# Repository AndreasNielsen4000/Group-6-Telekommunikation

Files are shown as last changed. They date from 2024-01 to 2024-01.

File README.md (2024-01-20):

# Security Access system
Created for course 34338 - Telecommunication programming projects with Arduino.

A door access security system for everyday use. The implemented log-on possibilities are RFID, PIN, and bluetooth from a mobile phone.

The system consists of three parts:

1. A node.js server running a temporary database (by design so we did not need to clear the database all the time).
2. An ESP8266 with:
   1. RFID Reader.
   2. Servo Motor ("Door/Lock").
   3. Buzzer.
3. An ESP32-WROOM-32 with:
   1. Liquid Crystal Display for user feedback as well as access admin menu.
   2. keypad.
   3. RGB LED for feedback.
   4. White LED ("Keypad light").
   5. Photoresistor (Controlling White LED).
   
If a user enters a PIN on the keypad, a request with a hashed version of the PIN is sent from the ESP32 to the ESP8266. If the ESP8266 has WiFi, it will pass the request on to the server.
If the response is valid and access is granted, the ESP8266 will open the door and send a request to the ESP32 to update the LCD and as well as the RGB LED.

If a user presents an RFID tag, and the ESP8266 has WiFi, it will pass the request on to the server.
If the response is valid and access is granted, the ESP8266 will open the door and send a request to the ESP32 to update the LCD and as well as the RGB LED.

Should the response in either case be invalid or access not granted, then the door will not open, and a request will be sent from the ESP8266 to the ESP32 to change the LCD and RGB LED accordingly.

Should the ESP8266 not have a WiFi connection, it will instead look in the EEPROM to check if a match is stored there.

On any access granted or access denied response from the server, the ESP8266 checks the locally stored information and any needed update to the local information is performed. This is only done on event-by-event basis, meaning not the entire local user database is updated each time.

## Responsibilities

| Functionalities | Main | Secondary|
|---|---|---|
| API | Mads | Maria |
| Server | Maria | Mads |
| LCD | Andreas | Alexander, Maria |
| LEDs | Mads | Maria |
| Buzzer | Christian | Lukas |
| Serial communication | Alexander | Lukas, Mads, Andreas |
| EEPROM | Lukas | Christian |
| RFID | Christian | Lukas |
| Keypad | Andreas | Alexander |
| Photoresistor | Maria | Mads |
| WiFi | Lukas | Mads |
| Bluetooth | Alexander | |
| Hash | Andreas | |
| Servo motor | Christian | |
|Final integration | Lukas, Alexander, Mads | |

## Circuit diagram
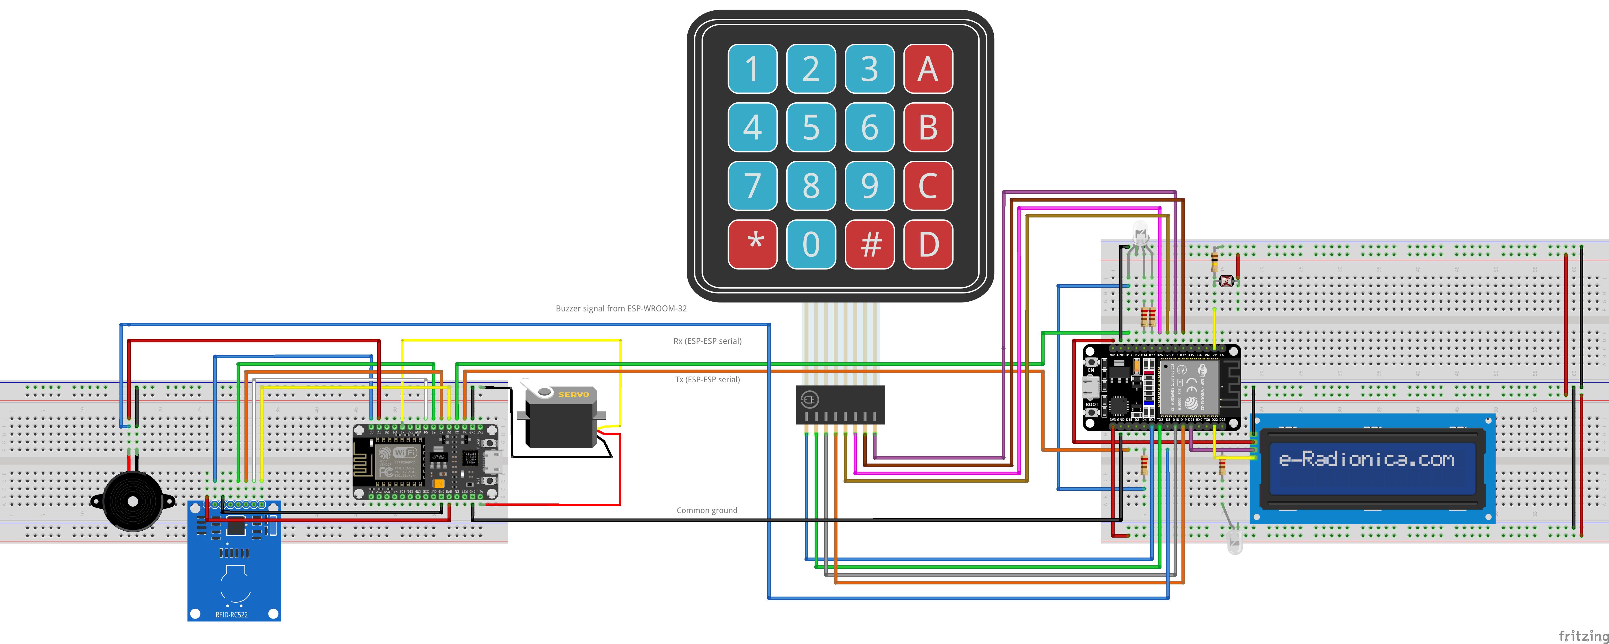
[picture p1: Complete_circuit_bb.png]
Complete setup


## Video Preview of Functionality

https://github.com/AndreasNielsen4000/Group-6-Telekommunikation/assets/8758884/5dff1484-a8b8-44ab-9b94-1a6748f98a57

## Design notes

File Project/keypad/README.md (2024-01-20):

# Keypad_ESP

## Keypad_ESP
Code for keypad part of project involving door access control running on two ESPs and a webserver.

## lcd_display
Code with class and functions to easily control the LCD display connected to the Keypad ESP.

## led_display
Code with class and functions to easily control status LED, light LED and buzzer sound on keypad keypress.

## hash
Simple function to hash passwords and RFID tags.

## Syntax for Serial Communication between ESPs

### From Keypad ESP to RFID ESP
Syntax:

 `<COMMAND>,<hashedPassword>(optional),<userIndex>(optional),<hashedMasterPassword>(optional)`

### Commands
From Keypad ESP to RFID ESP

`LOGIN`

`NEW_PASSWORD`

`NEW_RFID`

`CANCEL_RFID`

From RFID ESP to Keypad ESP

`ACCESS`

`ACCESS_DENIED`

`RFID_READ`

### Examples & Description:
#### User Login:
A login with a password (PIN) is attempted from the keypad.

Keypad Sends:

`LOGIN,<hashedPassword>, , `

#### New User Password:
From the admin menu on the keypad, a request to register a new password for a user is sent.

Keypad Sends:

`NEW_PASSWORD,<hashedPassword>,<userIndex>,<hashedMasterPassword>`

#### New User RFID:
From the admin menu on the keypad, a request to register a new RFID chip/card for a user is sent.

Keypad Sends:

`NEW_RFID, ,<userIndex>,<hashedMasterPassword>`

Cancel RFID registration: (Only used for information as the RFID part has a timeout of no key is presented)

`CANCEL_RFID, , , `

### From RFID ESP To Keypad ESP
Syntax: 

`<COMMAND>,<userIndex>(optional)`

### Examples:
#### User Has Logged In:
If a login was processed and access granted RFID ESP sends:

`ACCESS,<userIndex>`

#### Wrong Password:
If a login was processed and access denied RFID ESP sends:

`ACCESS_DENIED,`

#### New User RFID created:
After a new RFID has been read, the RFID ESP sends the following command to verify that the Keypad ESP can exit the menu:

`RFID_READ,`

If instead an RFID chip was not read or an error occured the RFID ESP will send:

`ACCESS_DENIED,`

## Circuit diagram
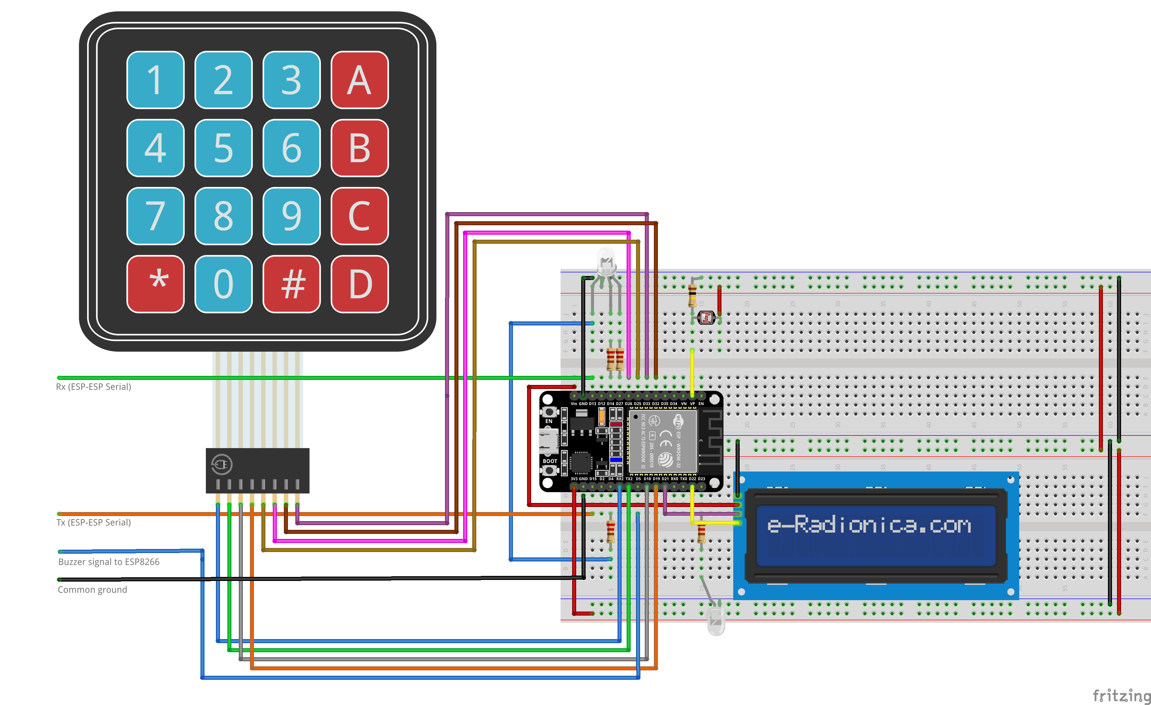
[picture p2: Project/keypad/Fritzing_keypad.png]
ESP32 Keypad setup


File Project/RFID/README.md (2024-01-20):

# RFID

## RFID
Code for RFID part of project involving door access control running on two ESPs and a webserver.

## api_caller
Library to support the requests and responses to/from the server

## hash
Simple function to hash passwords and RFID tags.

## Syntax for Serial Communication between ESPs

### From Keypad ESP to RFID ESP
Syntax:

 `<COMMAND>,<hashedPassword>(optional),<userIndex>(optional),<hashedMasterPassword>(optional)`

### Commands
From Keypad ESP to RFID ESP

`LOGIN`

`NEW_PASSWORD`

`NEW_RFID`

`CANCEL_RFID`

From RFID ESP to Keypad ESP

`ACCESS`

`ACCESS_DENIED`

`RFID_READ`

### Examples & Description:
#### User Login:
A login with a password (PIN) is attempted from the keypad.

Keypad Sends:

`LOGIN,<hashedPassword>, , `

#### New User Password:
From the admin menu on the keypad, a request to register a new password for a user is sent.

Keypad Sends:

`NEW_PASSWORD,<hashedPassword>,<userIndex>,<hashedMasterPassword>`

#### New User RFID:
From the admin menu on the keypad, a request to register a new RFID chip/card for a user is sent.

Keypad Sends:

`NEW_RFID, ,<userIndex>,<hashedMasterPassword>`

Cancel RFID registration: (Only used for information as the RFID part has a timeout of no key is presented)

`CANCEL_RFID, , , `

### From RFID ESP To Keypad ESP
Syntax: 

`<COMMAND>,<userIndex>(optional)`

### Examples:
#### User Has Logged In:
If a login was processed and access granted RFID ESP sends:

`ACCESS,<userIndex>`

#### Wrong Password:
If a login was processed and access denied RFID ESP sends:

`ACCESS_DENIED,`

#### New User RFID created:
After a new RFID has been read, the RFID ESP sends the following command to verify that the Keypad ESP can exit the menu:

`RFID_READ,`

If instead an RFID chip was not read or an error occured the RFID ESP will send:

`ACCESS_DENIED,`

## Circuit diagram
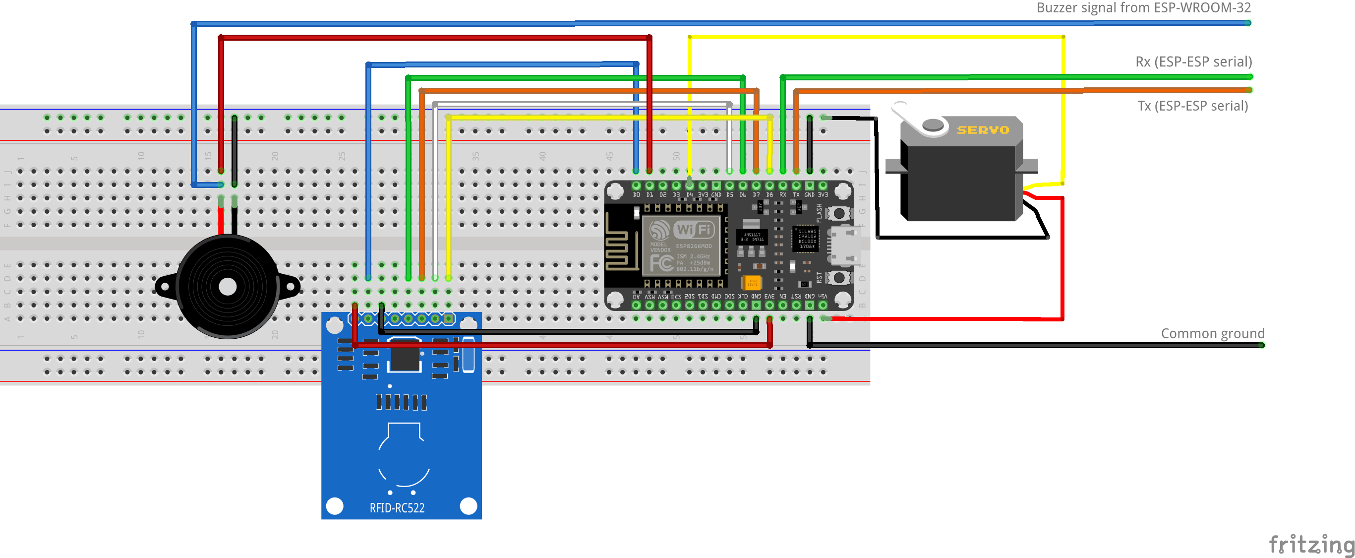
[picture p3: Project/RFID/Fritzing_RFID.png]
ESP8266 RFID setup


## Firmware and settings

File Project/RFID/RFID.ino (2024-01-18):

/*
  RFID.ino - This file contains the code for an ESP-based RFID system.
  It includes functionality for RFID input, EEPROM, serial communication between ESPs, WiFi setup and use of api_caller.
  It is meant to be used with an ESP8266 and communicates with another ESP through serial communication.
*/

#include <ArduinoJson.h>
#include <ESP8266HTTPClient.h>
#include <ESP8266WiFi.h>
#include <ESP_EEPROM.h>
#include <MFRC522.h>
#include <SPI.h>
#include <Servo.h>
#include <WiFiClientSecure.h>
#include <optional>

#include "Hash.h"
#include "api_caller.h"

#define SS_PIN D8 //MFRC522 SS pin ("slave select")
#define RST_PIN D0  //RESET pin for MFRC522
#define BUZZER_PIN D1 // Buzzer pin
#define NUM_USERS 5 // Number of users that can be saved in memory at the same time
#define KEYCARD_LENGTH 11 // Length of the keycard UID in bytes
#define MAX_MESSAGE_LENGTH 50 // Max length of the message from serial in bytes
#define OPEN_DOOR_TIME 5000  // The time the door is open in milliseconds
#define RFID_INTERVAL 5000  // Interval in milliseconds between RFID read
#define WIFI_INTERVAL 1000  // Interval in milliseconds between WiFi read
#define NEW_RFID_TIMEOUT 10000 // Time to read a new RFID before a timeout in milliseconds

MFRC522 mfrc522(SS_PIN, RST_PIN);  // Create MFRC522 instance.
Servo door_servo;

// Wifi credentials
const char *ssid = "";   /* Your SSID */
const char *pass = "";   /* Your Password */

const char *apiUrl = "http://172.20.10.5:8080"; /* Your API URL. Example: "https://api.example.com" */

// Global variables
unsigned long previous_RFID_Millis = 0;  // Will store last time the RFID was read
unsigned long previous_WIFI_Millis = 0;  // Will store last time the WIFI was updated
unsigned long currentMillis;
unsigned long adminPassword = hashPassword("12345678"); // adminpassword for the system

WiFiClient client;
ApiCaller apiCaller = ApiCaller(client, apiUrl);

// Struct for storing a user in memory (the pin and rfid are hashed)
struct User {
  unsigned long pin;
  unsigned long rfid;
};

// The array where the users are stored in memory (the pin and rfid are hashed)
User users[NUM_USERS] = {};

//Enum for the different received serial commands
enum SerialCommand {
  LOGIN,
  NEW_PASSWORD,
  NEW_RFID,
  CANCEL_RFID,
};

//Enum for the different serial responses
enum SerialSend {
  ACCESS_GRANTED,
  ACCESS_DENIED,
  RFID_READ,
  PIN_READ,
};

//Struct to store the command from serial communication and the associated data
struct CommandStruct {
  SerialCommand command;
  std::optional<unsigned long> password;
  std::optional<int> userIndex;
  std::optional<unsigned long> adminPassword;
};

struct ApiStruct {
  bool authenticated;
  int id;
};

bool connected_to_wifi(char retry_times);
std::optional<CommandStruct> processSerialCommunication();
void sendSerialResponse(SerialSend serialSend, int userIndex = -1);

void setup() {
  Serial.begin(115200);  // Initiate a serial communication

  EEPROM.begin(sizeof(User) * NUM_USERS);  // Initiate EEPROM memory size
  SPI.begin();                               // Initiate SPI bus
  mfrc522.PCD_Init();                        // Initiate MFRC522

  door_servo.attach(D4, 500, 2400);  // Attaches the servo on pin D4 to the servo object
  pinMode(BUZZER_PIN, OUTPUT);

  initialize_user_array_from_eeprom(); // Read the users array from EEPROM

  connected_to_wifi(3); // Try to connect to wifi 3 times
}

void loop() {
  // The loop is written in two parts, one for serial input and one for RFID input, serial input is based on the optionalCommand

  std::optional<CommandStruct> optionalCommand = processSerialCommunication();
  //Serial input section
  // There is a command from serial to be executed
  if (optionalCommand.has_value()) {
    CommandStruct cmd = optionalCommand.value();

    switch (cmd.command)
    {
    case SerialCommand::LOGIN: {
      // Check if the password is correct
      // in either api or local if no internet
      // save in EEPROM from API if it has changed
      if (connected_to_wifi(0)) {
        Serial.println("Calling api to check data");

        std::unique_ptr<DynamicJsonDocument> doc = apiCaller.GET("/pin", String(cmd.password.value()));
        if (doc == nullptr) {
          sendSerialResponse(SerialSend::ACCESS_DENIED);
          return;
        } 

        if (doc->containsKey("authenticated") ) {
          bool authenticated = (*doc)["authenticated"].as<bool>();
          if (authenticated) {
            int id = (*doc)["id"].as<int>();
            sendSerialResponse(SerialSend::ACCESS_GRANTED, id);
            if (users[id].pin != cmd.password.value()) {
              Serial.println("Found password in server but not in EEPROM, adding password to EEPROM");
              compare_and_update_pin(id, cmd.password.value());
            }
            
            access_tone();
            //Add to EEPROM at the correct index
            return;
          } else {
            sendSerialResponse(SerialSend::ACCESS_DENIED);
            for (int i = 0; i < NUM_USERS; i++) {
            if (users[i].pin == cmd.password.value()) {
              Serial.println("Found password in EEPROM but not in server, deleting from EEPROM");
              compare_and_update_pin(i, 0);
            }
          }
            no_access_tone();
            //If code is in EEPROM, remove it
            return;
          }
        } else {
          sendSerialResponse(SerialSend::ACCESS_DENIED);
          no_access_tone();
          return;
        }
        
      } else {
        bool access_granted = false;
        // Look in EEPROM
        for (int i = 0; i < NUM_USERS; i++) {
          if (users[i].pin == cmd.password.value()) {
            access_granted = true;
            sendSerialResponse(SerialSend::ACCESS_GRANTED, i);
            access_tone();
            return;
          }
        }

        if (access_granted == false) {
          sendSerialResponse(SerialSend::ACCESS_DENIED);
          no_access_tone();
        }
      }

      break; // LOGIN
    }
    case SerialCommand::NEW_RFID: {

      // You need to be connected to wifi to change the RFID
      if (!connected_to_wifi(0)) {
          sendSerialResponse(SerialSend::ACCESS_DENIED);
          return;
      }

      if (!cmd.adminPassword.has_value()) {
        Serial.println("No admin password");
        return;
      }

      // Check if the admin password is correct
      if (cmd.adminPassword.value() != adminPassword) {
        sendSerialResponse(SerialSend::ACCESS_DENIED);
        break;
      };

      // Get the new rfid code
      bool has_read_rfid = false;
      long new_rfid_millis = millis();

      unsigned long new_hashed_rfid = 0;

      do {
        if (!mfrc522.PICC_IsNewCardPresent()) {
          currentMillis = millis();
          continue;
        }
        if (!mfrc522.PICC_ReadCardSerial()) {
          continue;
        }
        Serial.println("Has read data");

        new_hashed_rfid = hashPassword(read_RFID().c_str());
        Serial.println(new_hashed_rfid);
        has_read_rfid = true;
      } while (!has_read_rfid && currentMillis - new_rfid_millis < NEW_RFID_TIMEOUT);

      if (!has_read_rfid) {
        sendSerialResponse(SerialSend::ACCESS_DENIED);
        break;
      }

      std::unique_ptr<DynamicJsonDocument> doc = apiCaller.PUT("/rfid", String(cmd.userIndex.value()), String(new_hashed_rfid));
      if (doc == nullptr) {
        sendSerialResponse(SerialSend::ACCESS_DENIED);
        break;
      } 

      if (doc->containsKey("success")) {
        bool succeeded = (*doc)["success"].as<bool>();
        if (succeeded) {

          Serial.println("Updated RFID");
          // Update the rfid in memory
          compare_and_update_rfid(cmd.userIndex.value(), new_hashed_rfid);

          sendSerialResponse(SerialSend::RFID_READ, cmd.userIndex.value());
          access_tone();
        } else {
          Serial.println("Failed to update RFID");
          sendSerialResponse(SerialSend::ACCESS_DENIED);
          no_access_tone();
        }
      } else {
        Serial.println("Failed to update RFID");
        sendSerialResponse(SerialSend::ACCESS_DENIED);
        no_access_tone();
      }

      break; // NEW_RFID
    }
    case SerialCommand::NEW_PASSWORD: {
      // You need to be connected to wifi to change the password
      if (!connected_to_wifi(0)) {
          sendSerialResponse(SerialSend::ACCESS_DENIED);
          return;
      }

      if (!cmd.adminPassword.has_value() && !cmd.password.has_value()) {
        Serial.println("No admin password or password");
        return;
      }

      // Check if the admin password is correct
      if (cmd.adminPassword.value() != adminPassword) {
        sendSerialResponse(SerialSend::ACCESS_DENIED);
        break;
      }

      std::unique_ptr<DynamicJsonDocument> doc = apiCaller.PUT("/pin", String(cmd.userIndex.value()), String(cmd.password.value()));
      if (doc == nullptr) {
        sendSerialResponse(SerialSend::ACCESS_DENIED);
        break;
      } 

      if (doc->containsKey("success")) {
        bool succeeded = (*doc)["success"].as<bool>();
        if (succeeded) {

          Serial.println("Updated PIN");
          // Update the pin in memory
          compare_and_update_pin(cmd.userIndex.value(), cmd.password.value());

          sendSerialResponse(SerialSend::PIN_READ, cmd.userIndex.value());
          access_tone();
        } else {
          Serial.println("Failed to update PIN");
          sendSerialResponse(SerialSend::ACCESS_DENIED);
          no_access_tone();
        }
      } else {
        Serial.println("Failed to update PIN");
        sendSerialResponse(SerialSend::ACCESS_DENIED);
        no_access_tone();
      }

    }
    default:
      // Should never reach here
      break;
    }
  }

  // RFID input section
    // Look for new cards
  if (!mfrc522.PICC_IsNewCardPresent()) {
    return;
  }
  // Select one of the cards
  if (!mfrc522.PICC_ReadCardSerial()) {
    return;
  }

  // Only read the UID if it is over the interval length since it has last been read
  currentMillis = millis();
  if (currentMillis - previous_RFID_Millis > RFID_INTERVAL) {
    bool access_granted = false;

    // Call api
    if (connected_to_wifi(0)) {
      Serial.println("Calling api to check data");
      unsigned long new_hashed_rfid = hashPassword(read_RFID().c_str());

      std::unique_ptr<DynamicJsonDocument> doc = apiCaller.GET("/rfid", String(new_hashed_rfid));
      if (doc == nullptr) {
        sendSerialResponse(SerialSend::ACCESS_DENIED);
        return;
      } 

      if (doc->containsKey("authenticated") ) {
        bool authenticated = (*doc)["authenticated"].as<bool>();
        if (authenticated) {
          int id = (*doc)["id"].as<int>();

          sendSerialResponse(SerialSend::ACCESS_GRANTED, id);
          
          if (users[id].rfid != new_hashed_rfid) {
            Serial.println("Found RFID in server but not in EEPROM, adding RFID to EEPROM");
            compare_and_update_rfid(id, new_hashed_rfid);
          }

          access_tone();
          return;
        } else {
          sendSerialResponse(SerialSend::ACCESS_DENIED);
          for (int i = 0; i < NUM_USERS; i++) {
            if (users[i].rfid == new_hashed_rfid) {
              Serial.println("Found RFID in EEPROM but not in server, deleting from EEPROM");
              compare_and_update_rfid(i, 0);
            }
          }
          
          no_access_tone();
          return;
        }
      } else {
        sendSerialResponse(SerialSend::ACCESS_DENIED);
        no_access_tone();
        return;
      }

    }

    // Look in EEPROM
    for (int i = 0; i < NUM_USERS; i++) {
      if (users[i].rfid == hashPassword(read_RFID().c_str())) {
        sendSerialResponse(SerialSend::ACCESS_GRANTED, i);
        access_granted = true;
        access_tone();
        break;
      }
    }

    if (access_granted == false) {
      sendSerialResponse(SerialSend::ACCESS_DENIED);
      no_access_tone();
    }
  }
}

/**
* Reads the UID of the RFID by collecting each byte together in on String
* Uses the MFRC522.h to read the bytes from the RFID
*
* @return the read RFID UID as a String
*/
String read_RFID() {
  previous_RFID_Millis = currentMillis;

  String content = "";

  byte letter;
  for (byte i = 0; i < mfrc522.uid.size; i++) { // Read 4 bytes from the RFID
    content.concat(String(mfrc522.uid.uidByte[i] < 0x10 ? " 0" : " "));// Add a leading zero to the UID bytes
    content.concat(String(mfrc522.uid.uidByte[i], HEX));  // Add the UID bytes to the content String
  }
  content.toUpperCase();
  return content.substring(1);  // return the UID
}


/*
* Save all of the pins and UIDs from the EEPROM to the user array
*/
void initialize_user_array_from_eeprom() {
  // Read the users array from EEPROM
  for (int i = 0; i < NUM_USERS; i++) {
    // Calculate the EEPROM address for the current user
    int address = i * sizeof(User);

    // Read the user data from EEPROM
    EEPROM.get(address, users[i]);
  }
}


/**
* Compares the new hashed pin with the old hashed pin and updates the pin if they are different
* It updates the pin in memory (users array) and in EEPROM
*
* @param user_index: the index of the user in the users array
* @param new_hashed_pin: the new hashed pin
*/
void compare_and_update_pin(int user_index, unsigned long new_hashed_pin) {
  if (users[user_index].pin != new_hashed_pin) {
    // Update the pin in user array
    users[user_index].pin = new_hashed_pin;

    // Update the pin in EEPROM
    int address = (user_index * 2) * sizeof(long);
    EEPROM.put(address, new_hashed_pin);
    EEPROM.commit();
  }
}  

/** 
* Compares the new hashed rfid with the old hashed rfid and updates the rfid if they are different
* It updates the rfid in memory (users array) and in EEPROM
*
* @param user_index: the index of the user in the users array
* @param new_hashed_rfid: the new hashed rfid
*/
void compare_and_update_rfid(int user_index, unsigned long new_hashed_rfid) {
  if (users[user_index].rfid != new_hashed_rfid) {
    // Update the rfid in user array
    users[user_index].rfid = new_hashed_rfid;

    // Update the rfid in EEPROM
    int address = (user_index * 2 + 1) * sizeof(long);
    EEPROM.put(address, new_hashed_rfid);
    EEPROM.commit();
  }
}

/*
* Plays a melody when the access is granted, and then the door opens and closes after a specified time
*/
void access_tone() {
  tone(BUZZER_PIN, 1046.5);
  delay(200);
  tone(BUZZER_PIN, 1174.66);
  delay(200);
  tone(BUZZER_PIN, 1318.51);
  delay(200);
  noTone(BUZZER_PIN);
  delay(800);
  tone(BUZZER_PIN, 1396.91);
  open_door();
  delay(300);
  noTone(BUZZER_PIN);
  delay(OPEN_DOOR_TIME - 300);
  close_door();
}

/**
* Plays a melody when the access was denied
*/
void no_access_tone() {
  tone(BUZZER_PIN, 932.33);
  delay(500);
  tone(BUZZER_PIN, 880);
  delay(500);
  tone(BUZZER_PIN, 830.61);
  delay(800);
  noTone(BUZZER_PIN);
}


void open_door() {
  door_servo.write(180);
}

void close_door() {
  door_servo.write(100);
}

/**
 * Connect to wifi with a number of retries
 *
 * @param retry_times: number of times to retry connecting to wifi. Default is 0
 * @return true if connected to wifi, false otherwise
 */
bool connected_to_wifi(char retry_times = 0){
  if (WiFi.status() == WL_CONNECTED) {
    Serial.println("Already connected to WiFi");
    return true;
  }
  Serial.println("WiFi not connected, connecting to WiFi SSID " + String(ssid));
  WiFi.begin(ssid, pass);
  // Waiting for WIFI connection
  char i = 0;
  while (WiFi.status() != WL_CONNECTED && i < retry_times) {
    delay(500);
    i++;
  }

  return WiFi.status() == WL_CONNECTED;
}

/**
 * Reads the serial input and processes it to extract command information.
 * 
 * @return An optional CommandStruct object containing the extracted command information, or std::nullopt if no commands were sent.
 */
std::optional<CommandStruct> processSerialCommunication() {
  // Read serial input
  char serialInput[MAX_MESSAGE_LENGTH] = {'\0'};
  CommandStruct commandStruct;
  commandStruct.adminPassword = std::nullopt;
  commandStruct.password = std::nullopt;
  commandStruct.userIndex = std::nullopt;

  if (Serial.available()) { // Check if there is serial data available
    Serial.readBytesUntil('\n', serialInput, MAX_MESSAGE_LENGTH);
    char* token = strtok(serialInput, ","); // Split the serial message using comma as the delimiter
    if (strcmp(token, "LOGIN") == 0) {
      commandStruct.command = SerialCommand::LOGIN;
    } else if (strcmp(token, "NEW_PASSWORD") == 0) {
      commandStruct.command = SerialCommand::NEW_PASSWORD;
    } else if (strcmp(token, "NEW_RFID") == 0) {
      commandStruct.command = SerialCommand::NEW_RFID;
    } else if (strcmp(token, "CANCEL_RFID") == 0) {
      commandStruct.command = SerialCommand::CANCEL_RFID;
    } else {
      // No commands sent
      return std::nullopt;
    }
    Serial.print("Command: ");
    Serial.println(commandStruct.command);  
    token = strtok(NULL, ","); // Get the next token (password)
    if (token != NULL && strlen(token) > 0 && strcmp(token, " ") != 0) {
      commandStruct.password = strtoul(token, NULL, 10); // Convert the password string to an unsigned long integer
      Serial.print("Password: ");
      Serial.println(commandStruct.password.value());
    }
    token = strtok(NULL, ","); // Get the next token (user index)
    if (token != NULL && strlen(token) > 0 && strcmp(token, " ") != 0) {
      commandStruct.userIndex = atoi(token); // Convert the user index string to an integer
      Serial.print("User index: ");
      Serial.println(commandStruct.userIndex.value());
    }
    token = strtok(NULL, ","); // Get the next token (admin password)
    if (token != NULL && strcmp(token, " ") != 0) {
      commandStruct.adminPassword = strtoul(token, NULL, 10); // Convert the admin password string to an unsigned long integer
      Serial.print("Admin password: ");
      Serial.println(commandStruct.adminPassword.value());
    }
    return commandStruct;
  }

  // No commands sent
  return std::nullopt;
}

/**
 * Sends a serial response based on the given SerialSend value and user index.
 * 
 * @param serialSend The type of serial response to send (ACCESS_GRANTED, ACCESS_DENIED, or RFID_READ).
 * @param userIndex The index of the user associated with the response, or -1 if no user is associated with the response.
 */
void sendSerialResponse(SerialSend serialSend, int userIndex) {
  switch (serialSend) {
    case SerialSend::ACCESS_GRANTED: //Access granted
      Serial.println("ACCESS," + String(userIndex));
      break;
    case SerialSend::ACCESS_DENIED: //Access denied
      Serial.println("ACCESS_DENIED," + String(userIndex));
      break;
    case SerialSend::RFID_READ: //We have read an RFID
      Serial.println("RFID_READ," + String(userIndex));
      break;
    default:
      break; // Should never reach here
  }
}

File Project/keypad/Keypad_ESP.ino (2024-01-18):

/*
  Keypad_ESP.ino - This file contains the code for an ESP-based keypad system.
  It includes functionality for keypad input, LCD display, LED control, and serial communication between ESPs.
  It is meant to be used with an ESP32 and communicates with another ESP through serial communication.
*/

#include <Keypad.h>
#include "Hash.h"
#include "lcd_display.h"
#include "led_control.h"
#include <BleSerial.h>

// Constants
#define MAX_MESSAGE_LENGTH 9
#define MAX_SERIAL_MESSAGE_LENGTH 150
#define NUM_USERS 5
#define RXD2 13 //define RX pin for serial2 communication (between ESPs)
#define TXD2 15 //define TX pin for serial2 communication (between ESPs)
// Pins for LED, light sensor and buzzer
#define RED_LED 4
#define GREEN_LED 14
#define BLUE_LED 27
#define WHITE_LED 23
#define LDR_PIN 36
#define BUZZER_PIN 5
// Rows and columns for keypad and keypad initialization
#define ROW_NUM 4 
#define COLUMN_NUM 4
//Keypad setup created with help from: https://arduinogetstarted.com/tutorials/arduino-keypad
byte rowPins[ROW_NUM] = {16, 17, 18, 19}; //connect to the row pinouts of the keypad
byte columnPins[COLUMN_NUM] = {25, 26, 32, 33}; //connect to the column pinouts of the keypad

// Variables for user and menu index
int menuIndex = 0;
int userIndex = 0;

// Function declarations
void adminMenuKeyPad(char *serialMessage);

char keypadKeys[ROW_NUM][COLUMN_NUM] = {
  {'1','2','3', 'A'},
  {'4','5','6', 'B'},
  {'7','8','9', 'C'},
  {'*','0','#', 'D'}
};


Keypad keypad = Keypad( makeKeymap(keypadKeys), rowPins, columnPins, ROW_NUM, COLUMN_NUM );

// Password for admin access
unsigned long adminPassword = hashPassword("12345678");

// Object declarations for LCD display, LED control and Bluetooth serial communication
lcd_display lcdDisplay;
led_control ledControl(RED_LED, GREEN_LED, BLUE_LED, WHITE_LED, LDR_PIN, BUZZER_PIN);
BleSerial SerialBT;

void setup() {
  Serial.begin(115200);
  Serial2.begin(115200, SERIAL_8N1, RXD2, TXD2);
  SerialBT.begin("KeypadBT"); //Bluetooth device name
  Serial.println("The device started, now you can pair it with bluetooth!");
  lcdDisplay.init();
  lcdDisplay.enterPasswordLCD("default"); //initial menu on lcd
  ledControl.init();
}

void loop() {
  char message[MAX_MESSAGE_LENGTH] = {'\0'}; //message array for keypad input
  char serialMessage[MAX_SERIAL_MESSAGE_LENGTH] = {'\0'}; //message array for serial input

  //Start main menu keypad function, changes the message array with keypad inputs
  mainMenuKeyPad(message, serialMessage);
  
  unsigned long messageHash = hashPassword(message);   
  ledControl.controlLED(0); //Set LED to idle status
  
  //If messageHash is not equal to the hash of an empty string, send the password to the other ESP through serial
  if (messageHash != hashPassword("\0")) {
    Serial2.println(String("LOGIN") + "," + String(messageHash) + "," + " " + ",");
    Serial.println(String("LOGIN") + "," + String(messageHash) + "," + " " + ",");
  }

  // If serialMessage is not empty, split the serial message from other ESP into message, accessGranted and userIndex, serial prints for debugging
  if (serialMessage[0] != '\0' && serialMessage[0] != '\r') {
    Serial.println("Serial message received from serial: " + String(serialMessage));
    parseSerialResponse(serialMessage);
  }
}

/**
 * Parses the serial response message and updates the access status based on the received information.
 * 
 * @param serialMessage The serial response message to parse.
 */
void parseSerialResponse(char *serialMessage) {
  int userIndex = -1;
  bool accessGranted = false;
  String tempMessage = "";
  tempMessage = serialMessage;
  char *token = strtok(serialMessage, ",");
  if (strcmp(token, "ACCESS") == 0) {
    accessGranted = true;
  } else if (strcmp(token, "ACCESS_DENIED") == 0) {
    accessGranted = false;
  } else {  // Not a valid message, must be a debug message from the other ESP - print it to the serial monitor and return
    Serial.println("Received: " + tempMessage);
    return;
  }
  token = strtok(NULL, ",");
  if (token != NULL) {
    userIndex = atoi(token);
  } else {
    userIndex = -1; // Set a default value for userIndex if not provided
  }
  updateAccessStatus(accessGranted, userIndex); //Gives feedback to user if password is correct or not through LED and LCD
}

/**
 * mainMenuKeyPad reads the keypad input in the main menu and performs actions based on the input.
 * It allows for the user to enter a password and send it to the other ESP through serial communication.
 * It also allows for the user to enter the admin menu by pressing D.
 * If the admin menu is entered, the adminMenuKeyPad function is called.
 * 
 * @param message The character array to store the keypad input message.
 * @param serialMessage The character array to store the serial input message.
 */
void mainMenuKeyPad(char *message, char *serialMessage) {
    static unsigned int messagePos = 0; // int to keep track of the position in the message array
    bool keyReceived = false;
    
    // Checking for keypad input, serial input, and Bluetooth input
    while (!keyReceived) {
        // If there is data available to read from the serial port, read it into the serial message buffer and exit the function
        if (checkSerialCommunication(serialMessage)) {
            if (messagePos > 0) {
                messagePos = 0;
                message[messagePos] = '\0';
            }
            return;
        }

        // Check if there is data available to read from the Bluetooth serial
        if (SerialBT.available()) {
            // Read the incoming data until a newline character is encountered
            String temp = SerialBT.readStringUntil('\n');
            // Convert the read String into a character array and store it in 'message'
            temp.toCharArray(message, temp.length() + 1);
            // If there is a message position, null-terminate the message at that position
            // and reset the message position
            if (messagePos > 0) {
                message[messagePos] = '\0';
                messagePos = 0;
                // Set the flag to indicate a key has been received
                keyReceived = true;
            }
            // Print a debug message to the serial monitor
            Serial.println("Serial BT message received in mainMenuKeyPad()");
            // Send a confirmation message back over Bluetooth serial
            SerialBT.println("Received");
            // Exit the function early since a key has been received
            return;
        }

        char key = keypad.getKey(); // Read keypad input
        ledControl.readLightSensor(); // Control light sensor
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

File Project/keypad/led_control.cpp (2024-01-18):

/*
* led_control.cpp
* Class and methods for controlling the LED and light sensor for the keypad
*/

#include "led_control.h"

led_control::led_control(int redPin, int greenPin, int bluePin, int lightPin, int ldrPin, int buzzerPin) : 
              PIN_RED(redPin), PIN_GREEN(greenPin), PIN_BLUE(bluePin), PIN_LIGHT(lightPin), LDRPin(ldrPin), buzzerPin(buzzerPin) {
}

//Initializes the LED and light sensor pins
void led_control::init() {
  pinMode(PIN_RED,   OUTPUT);
  pinMode(PIN_GREEN, OUTPUT);
  pinMode(PIN_BLUE,  OUTPUT);
  controlLED(0);
  pinMode(PIN_LIGHT, OUTPUT);
  pinMode(LDRPin, INPUT);
  pinMode(buzzerPin, OUTPUT);
}

//Controls the LED based on the status
void led_control::controlLED(int status) {
  switch(status){
    case 0: //Idle LED status
      analogWrite(PIN_RED,   0);
      analogWrite(PIN_GREEN, 0);
      analogWrite(PIN_BLUE,  255);
      break;
    case 1: //Access Granted LED status
      analogWrite(PIN_RED,   0);
      analogWrite(PIN_GREEN, 255);
      analogWrite(PIN_BLUE,  0);
      break;
    case 2: //Wrong Password LED status
      for (int i = 0; i < 5; i++){
        analogWrite(PIN_RED,   255);
        analogWrite(PIN_GREEN, 0);
        analogWrite(PIN_BLUE,  0);
        delay(300);
        analogWrite(PIN_RED,   0);
        analogWrite(PIN_GREEN, 0);
        analogWrite(PIN_BLUE,  0);
        delay(300);
      }
      break;
    case 9: //LED off status
      analogWrite(PIN_RED,   0);
      analogWrite(PIN_GREEN, 0);
      analogWrite(PIN_BLUE,  0);
      break;
    default: //Idle LED status
      analogWrite(PIN_RED,   0);
      analogWrite(PIN_GREEN, 0);
      analogWrite(PIN_BLUE,  255);
      break;
    
  }
}


//Reads the light sensor and turns on the light if it is dark, and turns it off if it is light.
void led_control::readLightSensor() {
  int lightValue = analogRead(LDRPin);
  if (lightValue < 2500){
    digitalWrite(PIN_LIGHT, HIGH);
  } else if (lightValue > 3000) {
    digitalWrite(PIN_LIGHT, LOW);
  }
}

//Blinks the LED and plays a tone when a key is pressed
void led_control::keyPressLED() {
    tone(buzzerPin, 698, 20);
    controlLED(9);
    delay(20);
    controlLED(0);
}

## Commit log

2024-01-10 Keypad 4x4 with Arduino and temp hash.h file
2024-01-15 Comments in RFID, Keypad, lcd and led, clean up in Keypad
2024-01-16 Fixed serial communication command handling
    [Keypad_ESP.ino, RFID.ino]
2024-01-20 General clean up
    [Fritzing_Keypad (2).fzz, RFID.fzz]
